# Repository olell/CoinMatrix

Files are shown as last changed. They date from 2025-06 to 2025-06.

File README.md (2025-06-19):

# CoinMatrix

CR2032 sized 8x8 pixel LED matrix driven by a CH32V003. This repo contains
firmware and hardware design files.

## Build the firmware
To build the firmware use the Makefile in the firmware subdirectory. To build
the project you need to clone ch32fun which is included as submodule in this
repo. To do that, run this command:
```
git submodule update --init
```

to build to firmware binary and flash it simply run `make` inside the firmware
directory.

## Hardware
You can find KiCad design files for the current hardware revision in the
hardware/ folder. ⚠️ V2 is currently untested and might have errors!

To view the projects in your browser you can use [KiCanvas](https://github.com/theacodes/kicanvas):
* [matrix board](https://kicanvas.org/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)
* [battery board](https://kicanvas.org/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)
* [spacer](https://kicanvas.org/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)

### Version 1 Pictures
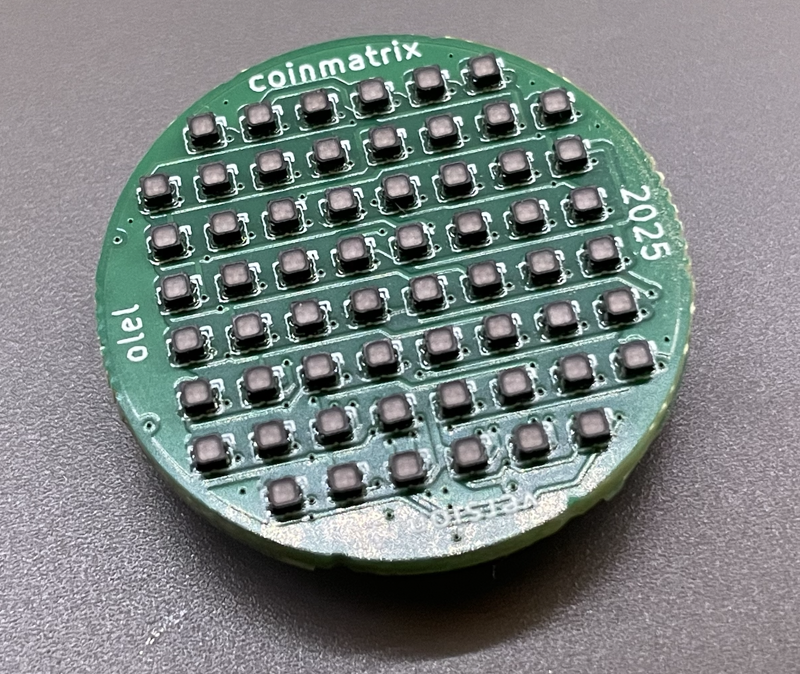
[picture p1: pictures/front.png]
front side

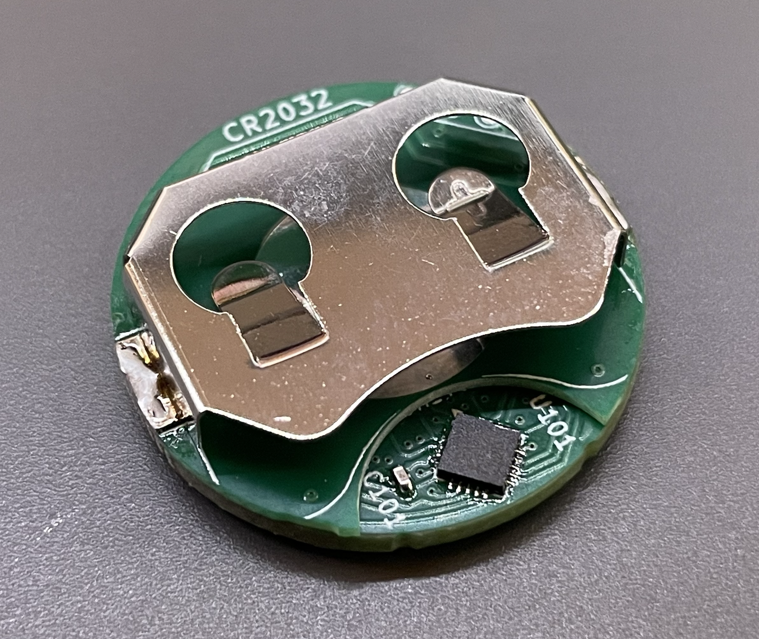
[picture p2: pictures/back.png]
back side


## License
The hardware is licensed under [CC BY-NC 4.0](https://creativecommons.org/licenses/by-nc/4.0/) you can find a copy of the license text in the LICENSE_HARDWARE file.

The firmware source code is licensed under MIT license, you can find a copy of the license text in the LICENSE file.

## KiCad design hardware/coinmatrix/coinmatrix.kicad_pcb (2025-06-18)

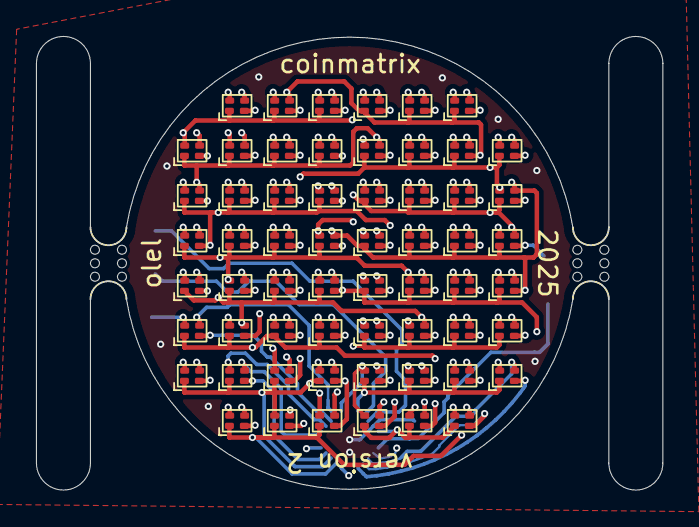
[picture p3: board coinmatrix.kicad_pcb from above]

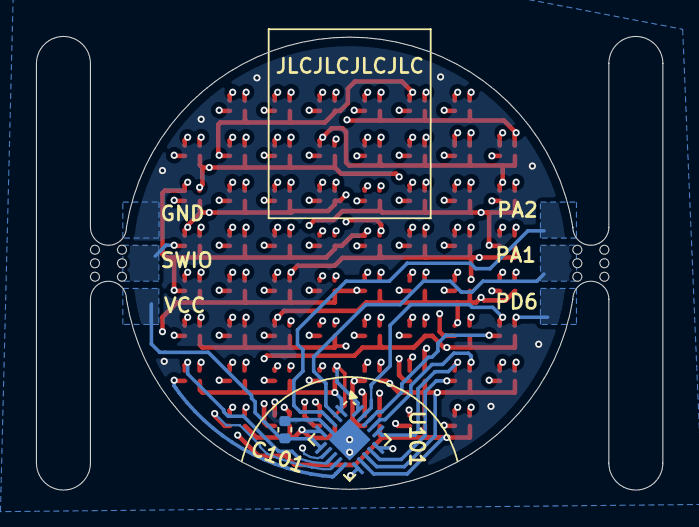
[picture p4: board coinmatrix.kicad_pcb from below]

Board: 4 copper layers, 34.8 x 25.2 mm, 64 parts (2 on the bottom side), 18 nets.

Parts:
C101: 100nF; C_0402_1005Metric
D102, D103, D104, D106, D107, D108, D109, D111, D112, D113, D114, D116, D117, D118, D119, D121, D122, D123, D124, D126, D127, D128, D129, D131, D132, D133, D134, D137, D138, D139, D141, D142, D143, D146, D147, D148, D149, D151, D152, D153, D154, D156, D157, D158, D159, D161, D162, D163, D164, D166, D167, D168, D169, D171, D172, D173, D174, D176, D177, D178: LED_RABG; LED-SMD-4P,1.2x1.2mm
U101: CH32V003FxUx; QFN-20-1EP_3x3mm_P0.4mm_EP1.65x1.65mm
mouse-bite-2mm-slot, mouse-bite-2mm-slot#2: VAL**; mouse-bite-2mm-slot

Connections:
/L0: D102.2 (A), D103.2 (A), D104.2 (A), D106.3 (BK), D111.3 (BK), D116.3 (BK), D121.3 (BK), D126.3 (BK), D131.3 (BK), D141.3 (BK), D146.3 (BK), D151.3 (BK), D156.3 (BK), D161.3 (BK), D166.3 (BK), D171.3 (BK), D176.3 (BK), U101.20 (PD6)
/L1: D106.2 (A), D107.2 (A), D108.2 (A), D109.2 (A), D111.4 (GK), D116.4 (GK), D121.4 (GK), D126.4 (GK), D131.4 (GK), D141.4 (GK), D146.4 (GK), D151.4 (GK), D156.4 (GK), D161.4 (GK), D166.4 (GK), D171.4 (GK), D176.4 (GK), U101.19 (PD5)
/L2: D106.4 (GK), D111.2 (A), D112.2 (A), D113.2 (A), D114.2 (A), D116.1 (RK), D121.1 (RK), D126.1 (RK), D131.1 (RK), D141.1 (RK), D146.1 (RK), D151.1 (RK), D156.1 (RK), D161.1 (RK), D166.1 (RK), D171.1 (RK), D176.1 (RK), U101.18 (PD4)
/L3: D106.1 (RK), D111.1 (RK), D116.2 (A), D117.2 (A), D118.2 (A), D119.2 (A), D122.3 (BK), D127.3 (BK), D132.3 (BK), D137.3 (BK), D142.3 (BK), D147.3 (BK), D152.3 (BK), D157.3 (BK), D162.3 (BK), D167.3 (BK), D172.3 (BK), D177.3 (BK), U101.17 (PD3)
/L4: D102.3 (BK), D107.3 (BK), D112.3 (BK), D117.3 (BK), D121.2 (A), D122.2 (A), D123.2 (A), D124.2 (A), D127.4 (GK), D132.4 (GK), D137.4 (GK), D142.4 (GK), D147.4 (GK), D152.4 (GK), D157.4 (GK), D162.4 (GK), D167.4 (GK), D172.4 (GK), D177.4 (GK), U101.16 (PD2)
/L5: D102.4 (GK), D107.4 (GK), D112.4 (GK), D117.4 (GK), D122.4 (GK), D126.2 (A), D127.2 (A), D128.2 (A), D129.2 (A), D132.1 (RK), D137.1 (RK), D142.1 (RK), D147.1 (RK), D152.1 (RK), D157.1 (RK), D162.1 (RK), D167.1 (RK), D172.1 (RK), D177.1 (RK), U101.14 (PC7)
/L6: D102.1 (RK), D107.1 (RK), D112.1 (RK), D117.1 (RK), D122.1 (RK), D127.1 (RK), D131.2 (A), D132.2 (A), D133.2 (A), D134.2 (A), D138.3 (BK), D143.3 (BK), D148.3 (BK), D153.3 (BK), D158.3 (BK), D163.3 (BK), D168.3 (BK), D173.3 (BK), D178.3 (BK), U101.13 (PC6)
/L7: D103.3 (BK), D108.3 (BK), D113.3 (BK), D118.3 (BK), D123.3 (BK), D128.3 (BK), D133.3 (BK), D137.2 (A), D138.2 (A), D139.2 (A), D143.4 (GK), D148.4 (GK), D153.4 (GK), D158.4 (GK), D163.4 (GK), D168.4 (GK), D173.4 (GK), D178.4 (GK), U101.12 (PC5)
/L8: D103.4 (GK), D108.4 (GK), D113.4 (GK), D118.4 (GK), D123.4 (GK), D128.4 (GK), D133.4 (GK), D138.4 (GK), D141.2 (A), D142.2 (A), D143.2 (A), D148.1 (RK), D153.1 (RK), D158.1 (RK), D163.1 (RK), D168.1 (RK), D173.1 (RK), D178.1 (RK), U101.9 (PC2)
/L9: D103.1 (RK), D108.1 (RK), D113.1 (RK), D118.1 (RK), D123.1 (RK), D128.1 (RK), D133.1 (RK), D138.1 (RK), D143.1 (RK), D146.2 (A), D147.2 (A), D148.2 (A), D149.2 (A), D154.3 (BK), D159.3 (BK), D164.3 (BK), D169.3 (BK), D174.3 (BK), U101.7 (PC0)
/L10: D104.3 (BK), D109.3 (BK), D114.3 (BK), D119.3 (BK), D124.3 (BK), D129.3 (BK), D134.3 (BK), D139.3 (BK), D149.3 (BK), D151.2 (A), D152.2 (A), D153.2 (A), D154.2 (A), D159.4 (GK), D164.4 (GK), D169.4 (GK), D174.4 (GK), U101.8 (PC1)
/L11: D104.4 (GK), D109.4 (GK), D114.4 (GK), D119.4 (GK), D124.4 (GK), D129.4 (GK), D134.4 (GK), D139.4 (GK), D149.4 (GK), D154.4 (GK), D156.2 (A), D157.2 (A), D158.2 (A), D159.2 (A), D164.1 (RK), D169.1 (RK), D174.1 (RK), U101.10 (PC3)
/L12: D104.1 (RK), D109.1 (RK), D114.1 (RK), D119.1 (RK), D124.1 (RK), D129.1 (RK), D134.1 (RK), D139.1 (RK), D149.1 (RK), D154.1 (RK), D159.1 (RK), D161.2 (A), D162.2 (A), D163.2 (A), D164.2 (A), U101.15 (PD1)
/L13: D166.2 (A), D167.2 (A), D168.2 (A), D169.2 (A), U101.11 (PC4)
/L14: D171.2 (A), D172.2 (A), D173.2 (A), D174.2 (A), U101.1 (PD7)
/L15: D176.2 (A), D177.2 (A), D178.2 (A), U101.5 (PD0)
GND: C101.1, U101.4 (VSS), U101.21 (VSS)
VCC: C101.2, U101.6 (VDD)

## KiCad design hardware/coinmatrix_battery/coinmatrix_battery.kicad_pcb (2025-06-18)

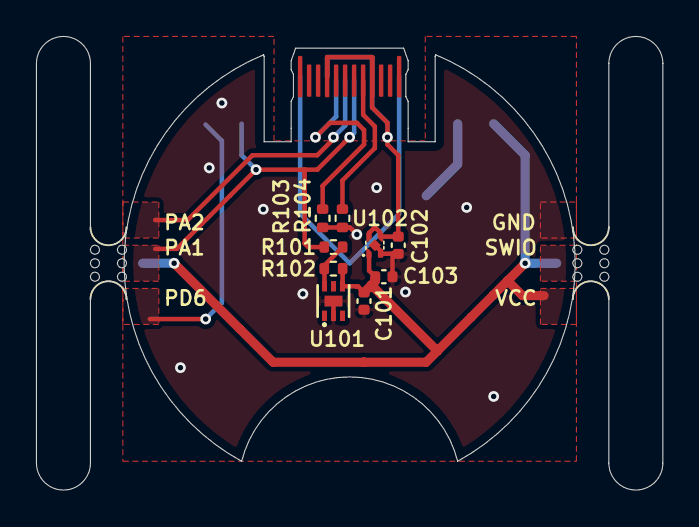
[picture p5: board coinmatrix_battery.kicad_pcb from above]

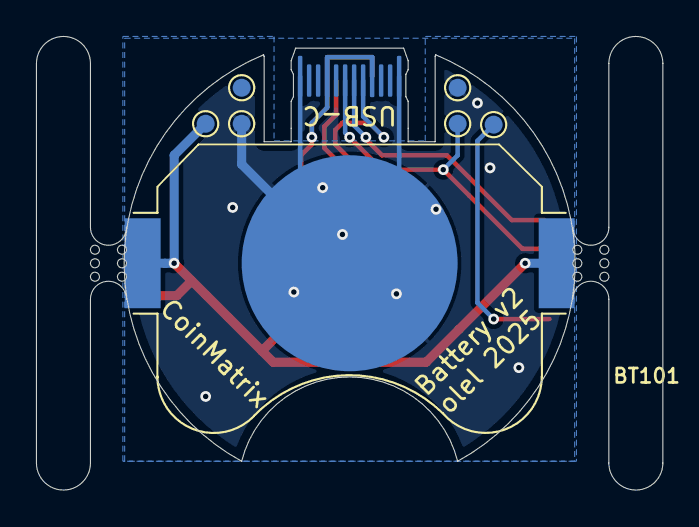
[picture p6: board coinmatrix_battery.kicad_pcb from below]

Board: 2 copper layers, 25.1 x 23.0 mm, 19 parts (8 on the bottom side), 7 nets.

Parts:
BT101: Battery_Cell; BatteryHolder_2032
C101: 100nF; C_0402_1005Metric
C102, C103: 1uF; C_0402_1005Metric
P101: USB_C_Plug; USB_C_PADDLE
R101, R103, R104: 5.1kΩ; R_0402_1005Metric
R102: 0; R_0402_1005Metric
TP101, TP102, TP103, TP104, TP105, TP106: TestPoint; TestPoint_Pad_D1.0mm
U101: HAL1255; DFN-6_L1.6-W1.6-P0.50-BL-EP1.0
U102: LW5233; DFN-4_L1.0-W1.0-P0.65-BL-EP
mouse-bite-2mm-slot, mouse-bite-2mm-slot#2: VAL**; mouse-bite-2mm-slot

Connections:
+5V: C102.1, P101.A4 (VBUS), P101.A9 (VBUS), P101.B4 (VBUS), P101.B9 (VBUS), U102.3 (EN), U102.4 (IN)
/DN: P101.A7 (D-), R101.2, TP104.1
/HALL: R101.1, R102.1, U101.6 (OUT)
GND: BT101.2 (-), C101.1, C102.2, C103.2, P101.A1 (GND), P101.A12 (GND), P101.B1 (GND), P101.B12 (GND), R103.2, R104.2, TP103.1, TP105.1, U101.2 (GND), U101.7, U102.2 (GND), U102.5 (EP)
unnamed: P101.A5 (CC), R103.1
unnamed: P101.B5 (VCONN), R104.1
VCC: BT101.1 (+), C101.2, C103.1, R102.2, TP102.1, U101.4 (VDD), U102.1 (OUT)

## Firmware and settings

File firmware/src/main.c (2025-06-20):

#include <stdint.h>
#include <stdio.h>

#include "animation.h"
#include "animations/animationPlayer.h"
#include "animations/cycle.h"
#include "animations/droplets.h"
#include "animations/firework.h"
#include "animations/matrix.h"
#include "animations/pac.h"
#include "animations/rolling_text.h"
#include "animations/gol.h"
#include "ch32fun.h"
#include "charlie.h"
#include "systick.h"

#define ANIMATION_CYCLE_INTERVAL 20000 // milliseconds between each animation change

static const animation_t* animations[MAX_ANIMATIONS];
static size_t animation_count = 0;
size_t current_animation_idx = 0;
const animation_t* current_animation;

void register_animation(const animation_t* anim) {
    if (animation_count < MAX_ANIMATIONS) {
        animations[animation_count++] = anim;
    }
}

const animation_t* get_animation(size_t index) {
    if (index >= animation_count) return NULL;
    return animations[index];
}

int main() {
    SystemInit();
    funGpioInitAll();
    systickInit();

    RCC->APB2PCENR |= RCC_APB2Periph_GPIOC | RCC_APB2Periph_GPIOD | RCC_APB2Periph_AFIO | RCC_AFIOEN;

    // register animations here
    register_animation(&gol_animation);
    register_animation(&droplets_animation);
    register_animation(&cycle_animation);
    register_animation(&pac_animation);
    register_animation(&animation_player);
    register_animation(&rolling_text_animation);
    register_animation(&firework_animation);
    register_animation(&matrix_animation);

    current_animation_idx = 0;
    current_animation = animations[current_animation_idx];
    current_animation->init();

    charlieSetup();

    uint32_t anim_start_time = millis();

    for (;;) {
        current_animation->tick();
        Delay_Ms(current_animation->tick_interval);
        if (millis() - anim_start_time > ANIMATION_CYCLE_INTERVAL) {
            anim_start_time = millis();
            if (++current_animation_idx >= animation_count)
                current_animation_idx = 0;
            current_animation = animations[current_animation_idx];
            current_animation->init();
        }
    }
}

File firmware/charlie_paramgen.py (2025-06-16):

import sys

# ch32v003 register addresses
GPIOC_OUTDR = 0x4001100C
GPIOD_OUTDR = 0x4001140C

# matrix hardware description
WD = 12 # width
HG = 16 # height

# pins used for charlieplexing, as tuples of ("PORT", PIN). Only GPIO C & D!
PINS = [ 
    ("D", 6),
    ("D", 5),
    ("D", 4),
    ("D", 3),
    ("D", 2),
    ("C", 7),
    ("C", 6),
    ("C", 5),
    ("C", 2),
    ("C", 0),
    ("C", 1),
    ("C", 3),
    ("D", 1),
    ("C", 4),
    ("D", 7),
    ("D", 0),
]

# precalculated config register values
conf_register_values = {
    "C": [],
    "D": []
}
# precalculated output register values
out_register_addresses = []
out_register_values = []

x = 0
x_idx = 1
y = 0
while 1:
    port_x, pin_x = PINS[x_idx]
    port_y, pin_y = PINS[y]

    cfg_x = 2 << (pin_x * 4)
    cfg_y = 2 << (pin_y * 4)

    out_x = 1 << (pin_x)
    out_y = 1 << (pin_y)

    if (port_x != port_y):
        # config register values
        conf_register_values[port_x].append(cfg_x)
        conf_register_values[port_y].append(cfg_y)
    else:
        conf_register_values[port_x].append(cfg_x | cfg_y)
        conf_register_values["C" if port_x == "D" else "D"].append(0)


    # todo: this code assumes the y pins are anodes
    if True:
        if port_y == "C":
            out_register_addresses.append(GPIOC_OUTDR)
        elif port_y == "D":
            out_register_addresses.append(GPIOD_OUTDR)
        out_register_values.append(out_y)
    else:
        if port_x == "C":
            out_register_addresses.append(GPIOC_OUTDR)
        elif port_x == "D":
            out_register_addresses.append(GPIOD_OUTDR)
        out_register_values.append(out_x)
    

    print(f"x, y: {x_idx}, {y}", file=sys.stderr)

    x += 1
    x_idx += 1
    if (x_idx == y): x_idx += 1
    if (x >= WD):
        x = 0
        x_idx = 0
        y += 1
        if (y == HG):
            break


mem_usage = len(conf_register_values["C"])
print(f"#define CHARLIE_CYCLE_COUNT {mem_usage}")
print(f"const uint32_t charlie_gpioc_cfglr[CHARLIE_CYCLE_COUNT] = {{{', '.join(list(map(lambda x: f"0x{x:08x}", conf_register_values["C"])))}}};")
print(f"const uint32_t charlie_gpiod_cfglr[CHARLIE_CYCLE_COUNT] = {{{', '.join(list(map(lambda x: f"0x{x:08x}", conf_register_values["D"])))}}};")
print(f"const uint32_t charlie_out_regs[CHARLIE_CYCLE_COUNT] = {{{', '.join(list(map(lambda x: f"0x{x:08x}", out_register_addresses)))}}};")
print(f"const uint8_t charlie_out_vals[CHARLIE_CYCLE_COUNT] = {{{', '.join(list(map(lambda x: f"0x{x:02x}", out_register_values)))}}};")

print("Memory usage:", file=sys.stderr)
flash = 13 * mem_usage # uint32_t = 4 bytes, uint8_t = 1 byte -> 3 * 4 + 1 = 13
print(f"Flash: {flash} bytes", file=sys.stderr)
print(f"RAM: {mem_usage} bytes", file=sys.stderr)

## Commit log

2025-06-17 ⚰️ remove unused usb code
2025-06-17 ✨ enabled animation cycling
2025-06-17 🔥 remove ledvm
2025-06-17 🚑 add ch32fun include for systick counter
2025-06-18 🐛 fix unexpected behavior of charlieDisplay
    [charlie.c]
2025-06-18 🙈 Added kicad to gitignore
2025-06-18 ✨ add v2 hardware design files
    [coinmatrix.kicad_pcb, coinmatrix.kicad_sch, coinmatrix_battery.kicad_pcb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]
2025-06-18 💫 enable droplets animation
2025-06-19 ✨ add gif script and move reset script to subdir
2025-06-19 👷 add build action
2025-06-19 📝 add license, some documentation and pictures
2025-06-20 💫 add game of life animation
